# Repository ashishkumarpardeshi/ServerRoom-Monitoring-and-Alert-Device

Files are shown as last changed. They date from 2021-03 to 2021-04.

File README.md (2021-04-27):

# ServerRoom-Monitoring-and-Alert-Device

<p align="center">
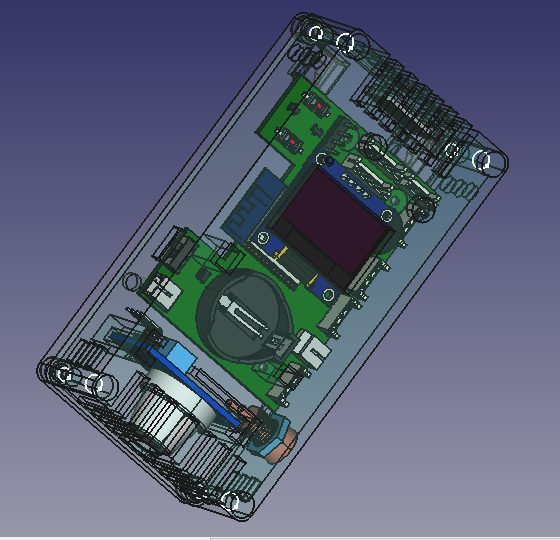
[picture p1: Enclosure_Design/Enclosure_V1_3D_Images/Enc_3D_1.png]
  
</p>

<p align="center">
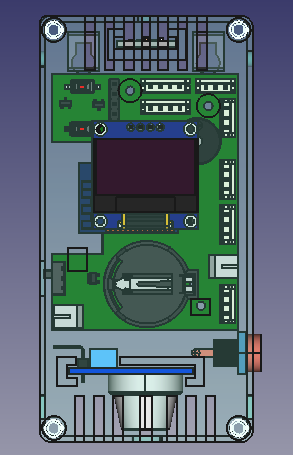
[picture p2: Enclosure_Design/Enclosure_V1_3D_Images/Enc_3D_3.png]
  
</p>

<p align="center">
  
</p>

<p align="center">
  
</p>

<p align="center">
  
</p>

<p align="center">
  
</p>

<p align="center">
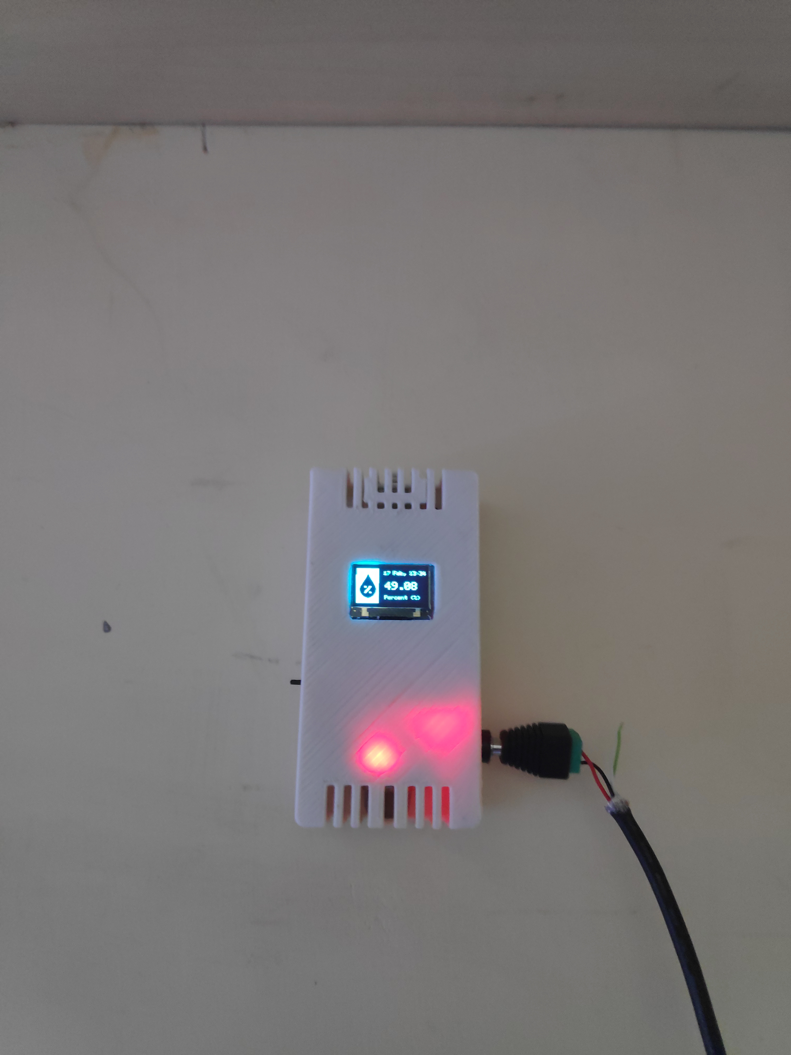
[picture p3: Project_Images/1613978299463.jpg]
  
</p>

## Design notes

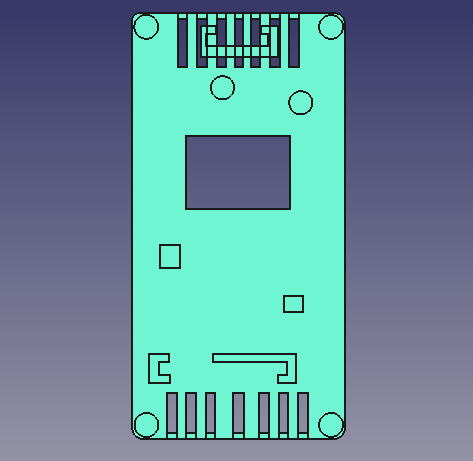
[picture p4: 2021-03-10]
Enclosure_Design/Enclosure_V1_3D_Images/Enc_3D_19.png

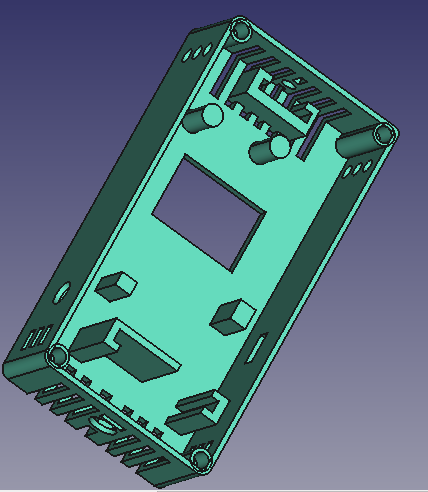
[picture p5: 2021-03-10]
Enclosure_Design/Enclosure_V1_3D_Images/Enc_3D_20.png

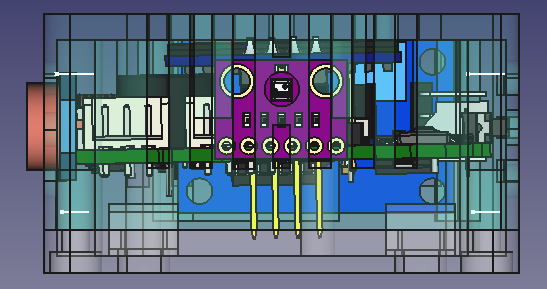
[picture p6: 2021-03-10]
Enclosure_Design/Enclosure_V1_3D_Images/Enc_3D_5.png

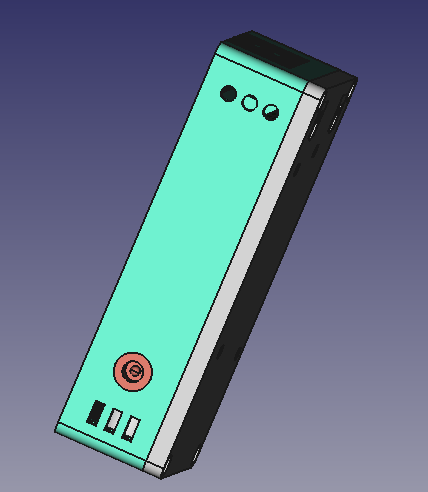
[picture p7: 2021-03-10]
Enclosure_Design/Enclosure_V1_3D_Images/Enc_3D_13.png

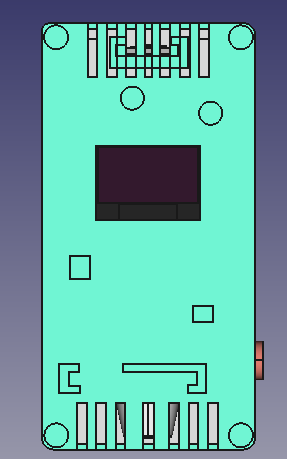
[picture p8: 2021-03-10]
Enclosure_Design/Enclosure_V1_3D_Images/Enc_3D_9.png

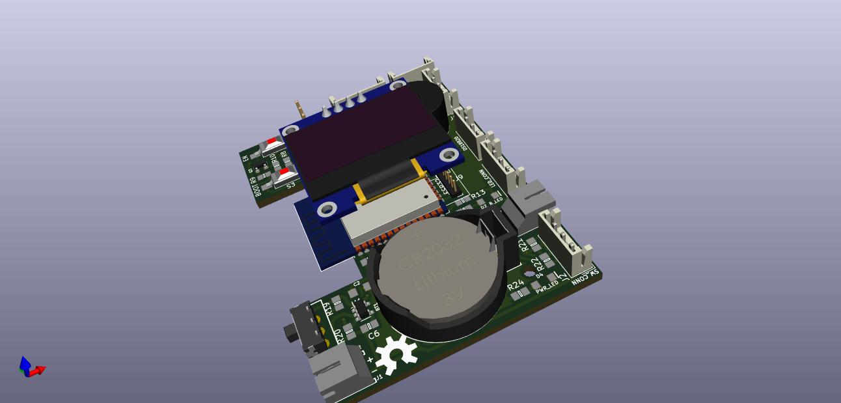
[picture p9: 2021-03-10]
PCB Design/PCB_Images/PWS9.jpg

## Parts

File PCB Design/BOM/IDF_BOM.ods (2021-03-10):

ESP32 Based Generic IoT_Deployement board
Component Count : 64
Individual Components :
Item | Reference(s) | Value | Footprint | Field4
OLED 128 x 64 | Brd1 | SSD1306 | SSD1306:128x64OLED
Battery Holder | BT1 | BAT 20MM PTH | Batteries:BATTCOM_20MM_PTH | BATT-09031
Capacitors | C1 | 1 UF | 805 | CAP-08064
 | C2 | 10UF | Capacitors:EIA3216 | CAP-00811
 | C3 | 0.1 UF | 805 | CAP-08064
 | C4 | 0.1 UF | 805 | CAP-08064
 | C5 | 0.1 UF | 805 | CAP-08064
 | C6 | 470 pF | 805 | CAP-08064
 | C7 | 2.2 uF | 805 | CAP-08064
 | C8 | 10UF | Capacitors:EIA3216 | CAP-00811
 | C9 | 0.1 UF | 805 | CAP-08064
 | C10 | 10UF | Capacitors:EIA3216 | CAP-00811
 | C11 | 0.1 UF | 805 | CAP-08064
Diodes | D1 | 1N4001 | Diode_SMD:D_0805_2012Metric
 | D2 | B_LED | LED:LED-1206 | DIO-09911
 | D3 | 1N4001 | Diode_SMD:D_0805_2012Metric
 | D4 | PWR_LED | LED:LED-1206 | DIO-09911
Connectors (JST & Pin Header) | J1 | PWR | Connectors:JST-2-PTH | CONN-09863
 | J2 | Switch_Conn | Connector_JST:JST_EH_B3B-EH-A_1x03_P2.50mm_Vertical | CONN-13230
 | J3 | Soil_Moisture | Connector_JST:JST_EH_B3B-EH-A_1x03_P2.50mm_Vertical | CONN-13230
 | J4 | LED_CONN | Connector_JST:JST_EH_B3B-EH-A_1x03_P2.50mm_Vertical | CONN-13230
 | J5 | Pump_Conn | Connectors:JST-2-PTH | CONN-09863
 | J6 | BH1750 | Connector_JST:JST_EH_B4B-EH-A_1x04_P2.50mm_Vertical | CONN-13251
 | J7 | HTUI2D | Connector_JST:JST_EH_B4B-EH-A_1x04_P2.50mm_Vertical | CONN-13251
 | J8 | Prog_Header | Connector_PinHeader_2.54mm:PinHeader_1x06_P2.54mm_Vertical
 | J9 | CONN_10 | Connector_PinHeader_1.27mm:PinHeader_1x10_P1.27mm_Vertical | XXX-00000
 | J10 | DHT22 | Connector_JST:JST_EH_B3B-EH-A_1x03_P2.50mm_Vertical | CONN-13230
 | J11 | DS18B20 | Connector_JST:JST_EH_B3B-EH-A_1x03_P2.50mm_Vertical | CONN-13230
Buzzer | LS1 | BUZ-PTH | Electromechanical:BUZZER-12MM | COMP-08253
ESP32 Wroom | MOD1 | ESP32-WROOM | RF_Module:ESP32-WROOM-32
Transistors | Q1 | MMBT2222A2 | Silicon-Standard:SOT23-3 | TRANS-08049
 | Q2 | MMBT2222A2 | Silicon-Standard:SOT23-3 | TRANS-08049
 | Q3 | MMBT2222A2 | Silicon-Standard:SOT23-3 | TRANS-08049
 | Q4 | MMBT2222A2 | Silicon-Standard:SOT23-3 | TRANS-08049
Resistors | R1 | 1k | 805
 | R2 | 10k | 805
 | R3 | 10k | 805
 | R4 | 10k | 805
 | R5 | 470e | 805
 | R6 | 470e | 805
 | R7 | 1k | 805
 | R8 | 10k | 805
 | R9 | 10k | 805
 | R10 | 10k | 805
 | R11 | 10k | 805
 | R12 | 10k | 805
 | R13 | 10k | 805
 | R14 | 470e | 805
 | R15 | 10k | 805
 | R16 | 805 | 805
 | R17 | 805 | 805
 | R18 | 10k | 805
 | R19 | 805 | 805
 | R20 | 805 | 805
 | R21 | 10k | 805
 | R22 | 10k | 805
 | R23 | 470e | 805
 | R24 | 470e | 805
Switches | S1 | ON/OFF | Switches:SWITCH_SPDT_PTH_11.6X4.0MM | SWCH-08261
 | S3 | Boot | Button_Switch_SMD:SW_SPST_FSMSM | SWCH-09213
 | S4 | EN | Button_Switch_SMD:SW_SPST_FSMSM | SWCH-09213
ICs (Voltage Reg, RTC) | U1 | MIC5219-3v3 | Package_TO_SOT_SMD:SOT-23-5
 | U2 | DS3231M | Package_SO:SOIC-16W_7.5x10.3mm_P1.27mm
 | U3 | AMS1117-3.3 | Package_TO_SOT_SMD:SOT-223-3_TabPin2

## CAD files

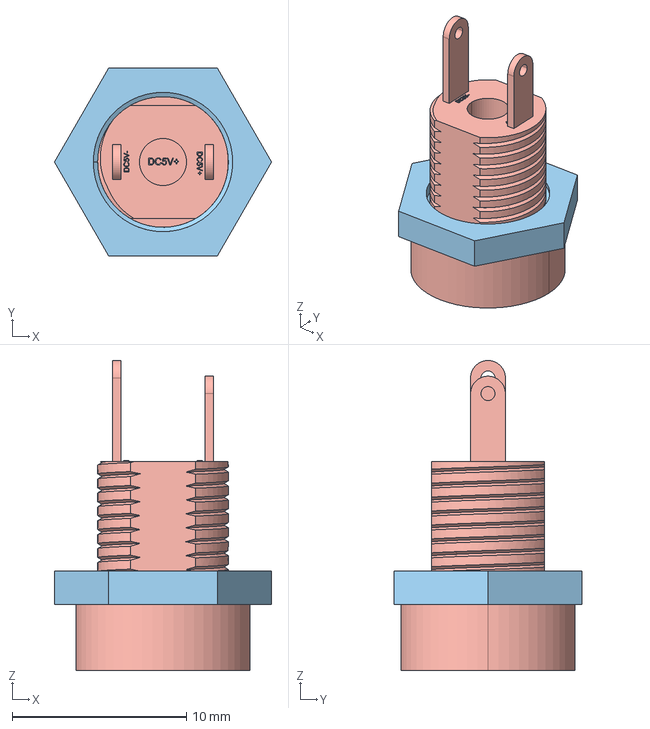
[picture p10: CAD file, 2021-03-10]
Enclosure_Design/Enclosure_V1_FreeCAD_Files/dc5v_jack_asm.stp
12.5 x 10.8 x 17.8 mm
DC5V_JACK
DC5V_JACK_NUTM8

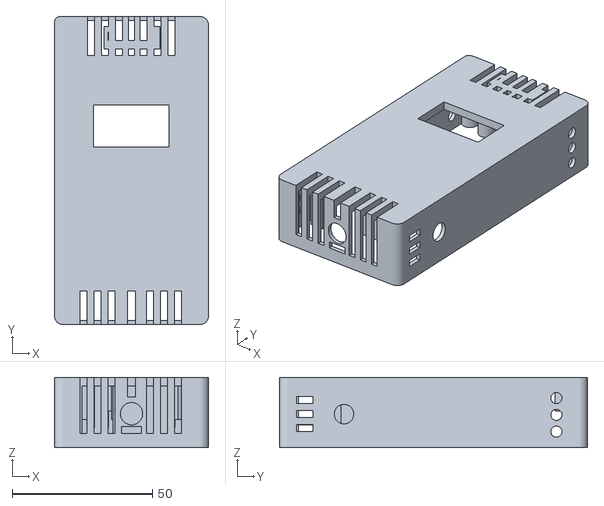
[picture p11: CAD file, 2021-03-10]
Enclosure_Design/Enclosure_V1_FreeCAD_Files/Main_Circuit_Enc.stl
55.0 x 110.0 x 25.0

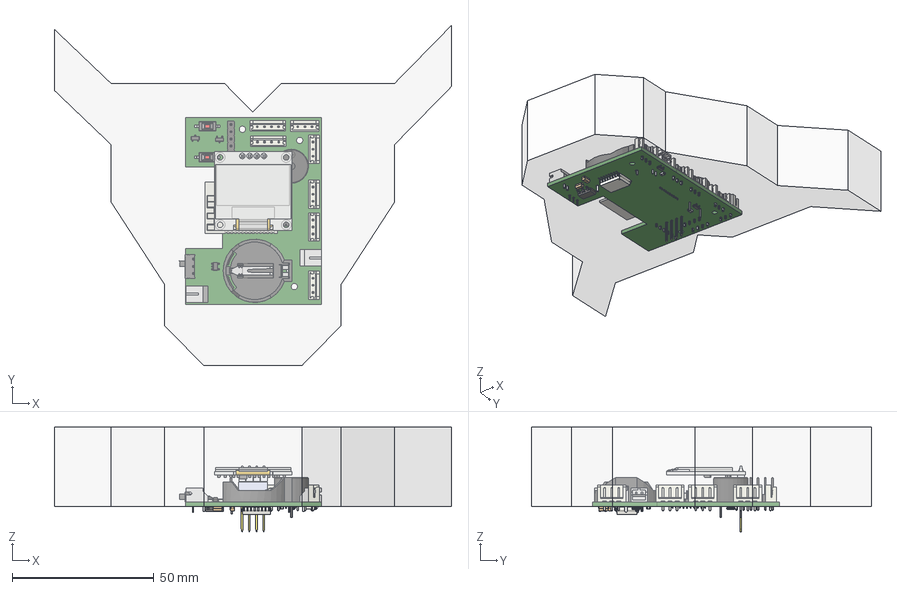
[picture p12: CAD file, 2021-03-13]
Enclosure_Design/Enclosure_V2/Enclosure_V2.FCStd
140.0 x 120.0 x 37.0 mm
Buffalo_Face_Sketch

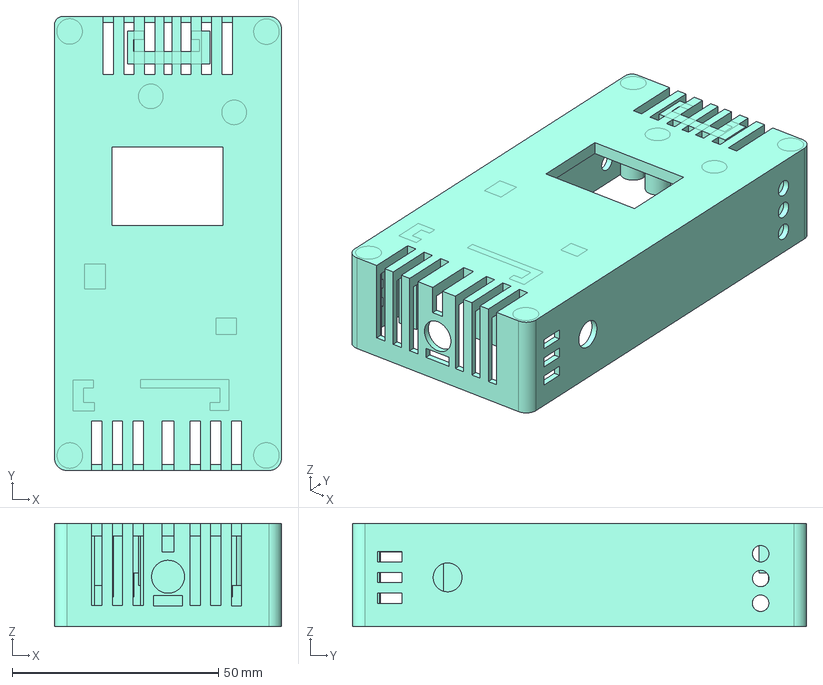
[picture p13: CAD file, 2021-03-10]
Enclosure_Design/Enclosure_V1_FreeCAD_Files/Serverroom_MDev.FCStd
55.0 x 110.0 x 25.0 mm

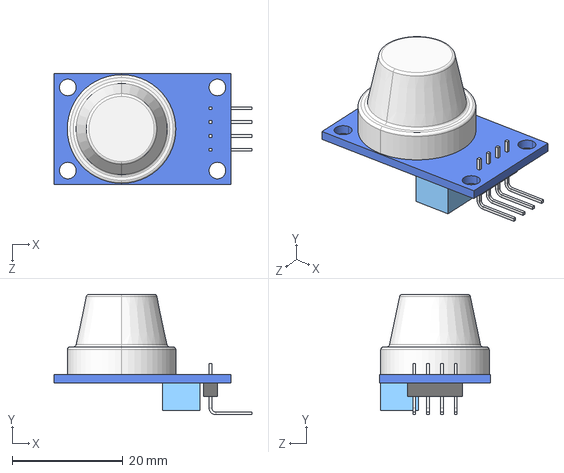
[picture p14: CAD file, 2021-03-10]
Enclosure_Design/Enclosure_V1_FreeCAD_Files/Датчик газа MQ2 (дым).STEP
35.8 x 21.8 x 20.0 mm

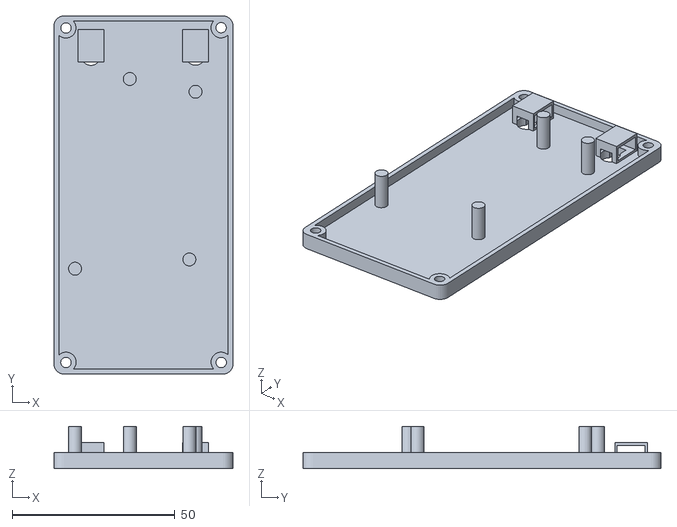
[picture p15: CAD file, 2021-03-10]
Enclosure_Design/Enclosure_V1_FreeCAD_Files/Lid_Enc.stl
55.0 x 110.0 x 13.0

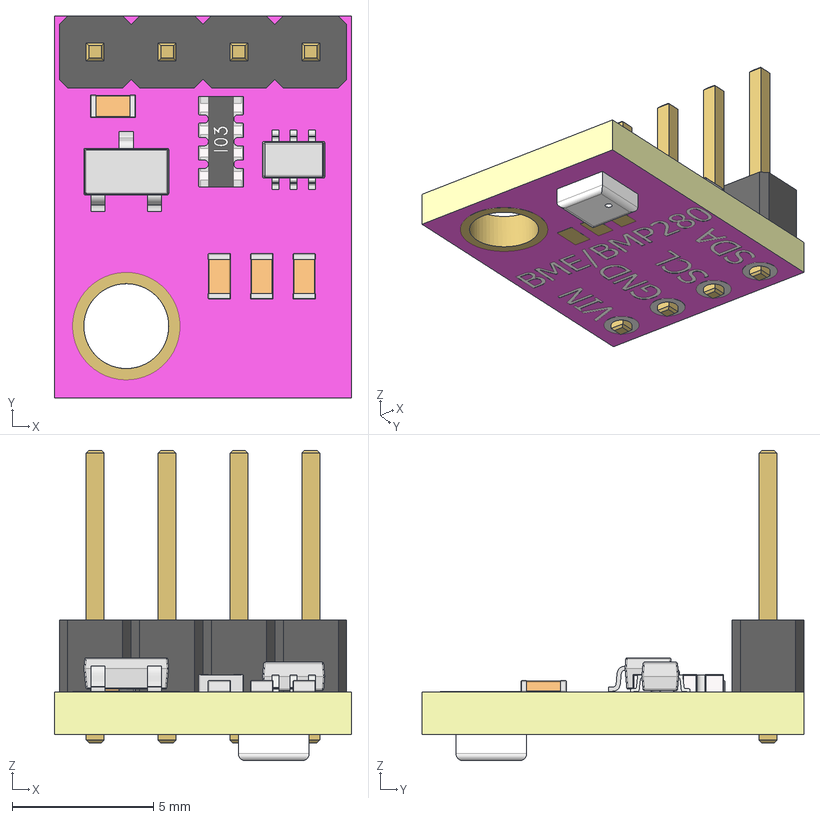
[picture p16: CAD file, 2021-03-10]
Enclosure_Design/Enclosure_V1_FreeCAD_Files/Sensor BME280 (1).stp
10.5 x 13.5 x 11.0 mm
плата датчика BME280
SOT-363
PLS-4
Сборка 0805 4x
SOT23-3

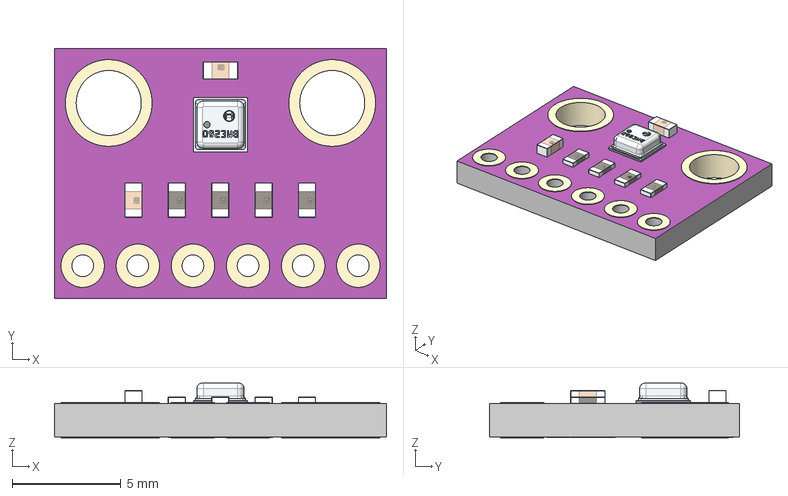
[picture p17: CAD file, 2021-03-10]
Enclosure_Design/Enclosure_V1_FreeCAD_Files/P280, 6-PIN-Version v4 (1).step
15.3 x 11.5 x 2.52 mm
Komponente1
Komponente2
Komponente3
Komponente4
Komponente5
Komponente6
Komponente7
Komponente8
Beschriftung
C0603 x 2
R0603 x 4
BME280

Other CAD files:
Enclosure_Design/Enclosure_V1_FreeCAD_Files/main_enc.step
Enclosure_Design/Enclosure_V1_FreeCAD_Files/lid.step

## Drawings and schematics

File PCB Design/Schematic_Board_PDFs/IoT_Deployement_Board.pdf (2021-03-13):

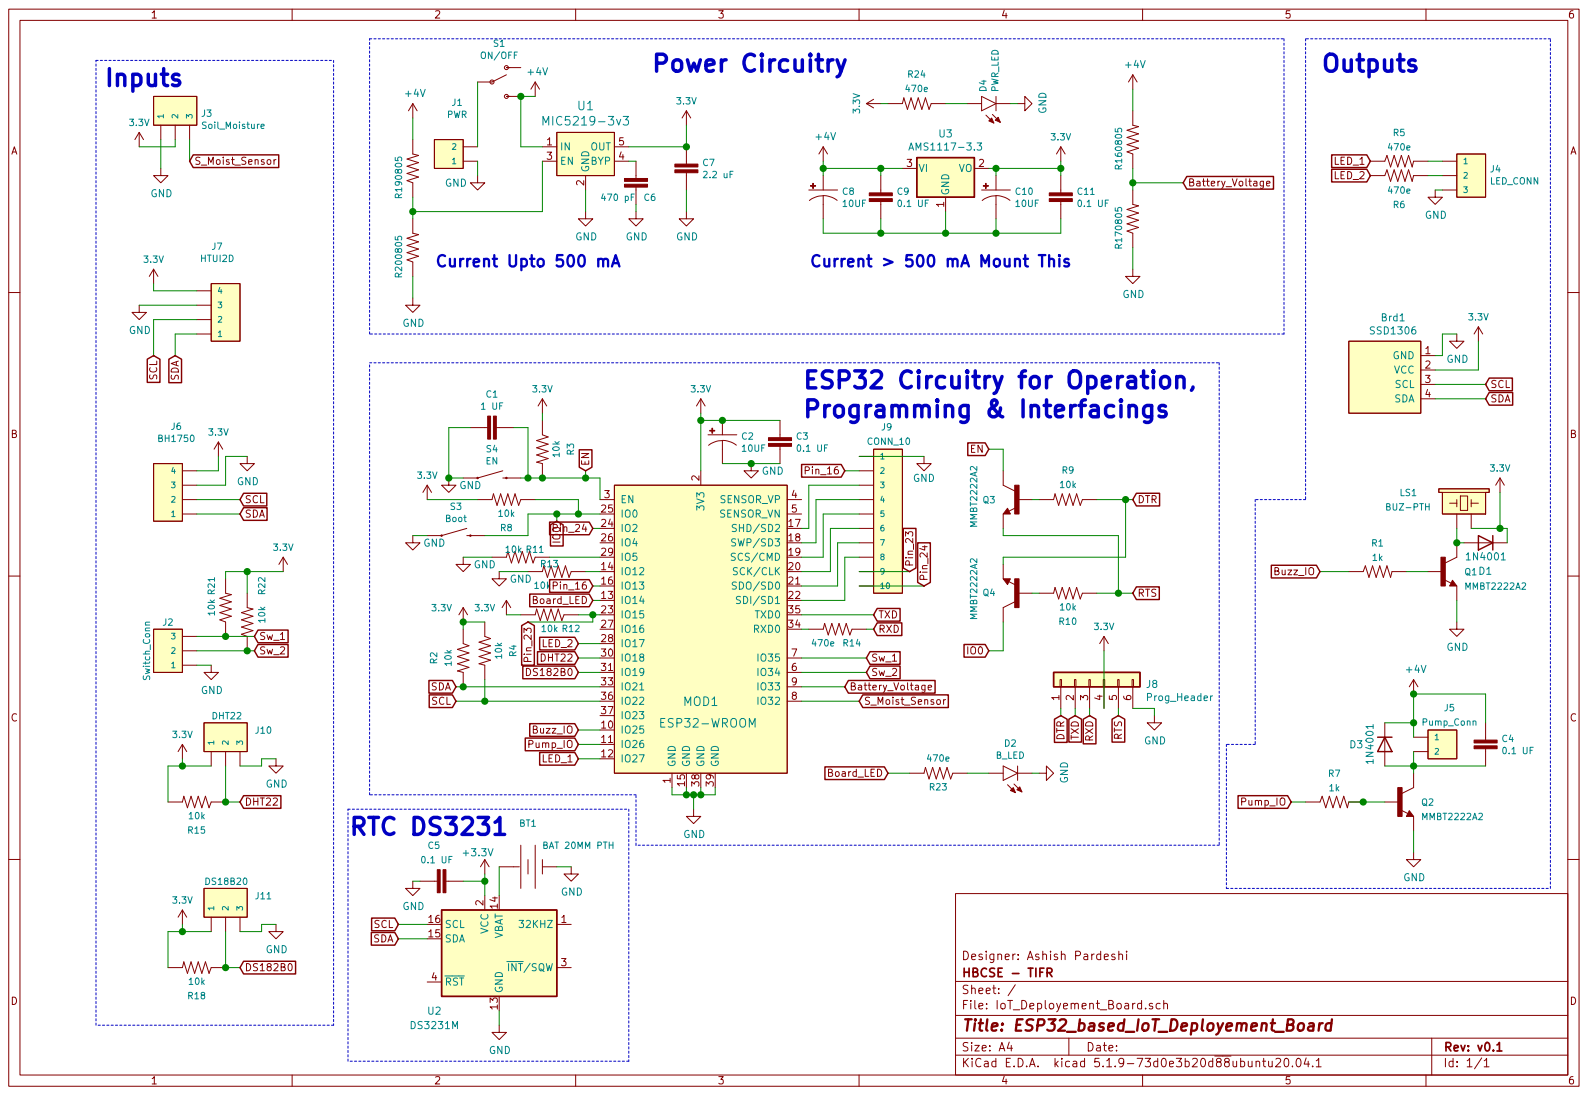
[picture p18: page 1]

Designer: Ashish Pardeshi 470e R14 GND
IO0 SCL

File: IoT_Deployement_Board.sch Sheet: / HBCSE - TIFR

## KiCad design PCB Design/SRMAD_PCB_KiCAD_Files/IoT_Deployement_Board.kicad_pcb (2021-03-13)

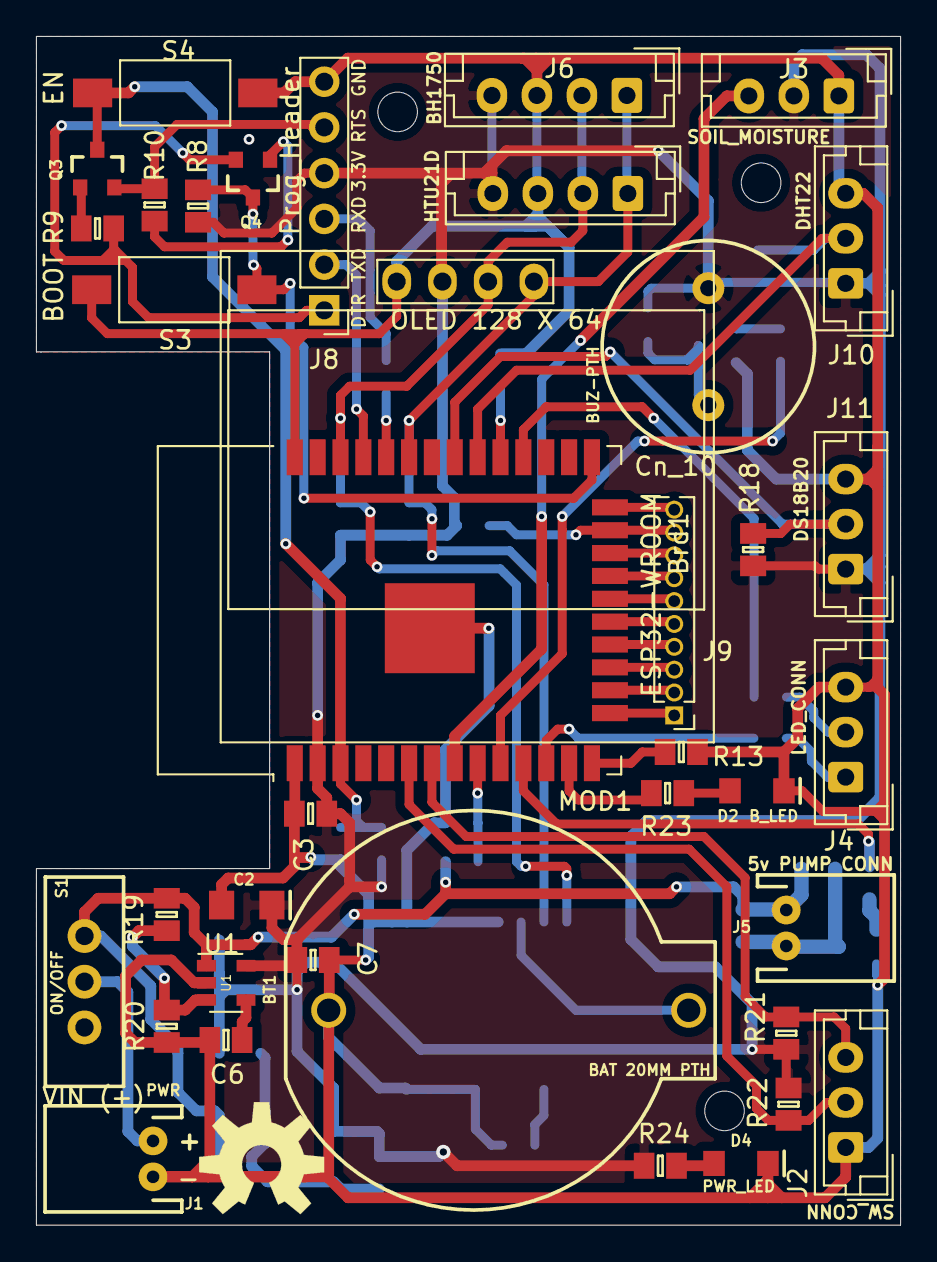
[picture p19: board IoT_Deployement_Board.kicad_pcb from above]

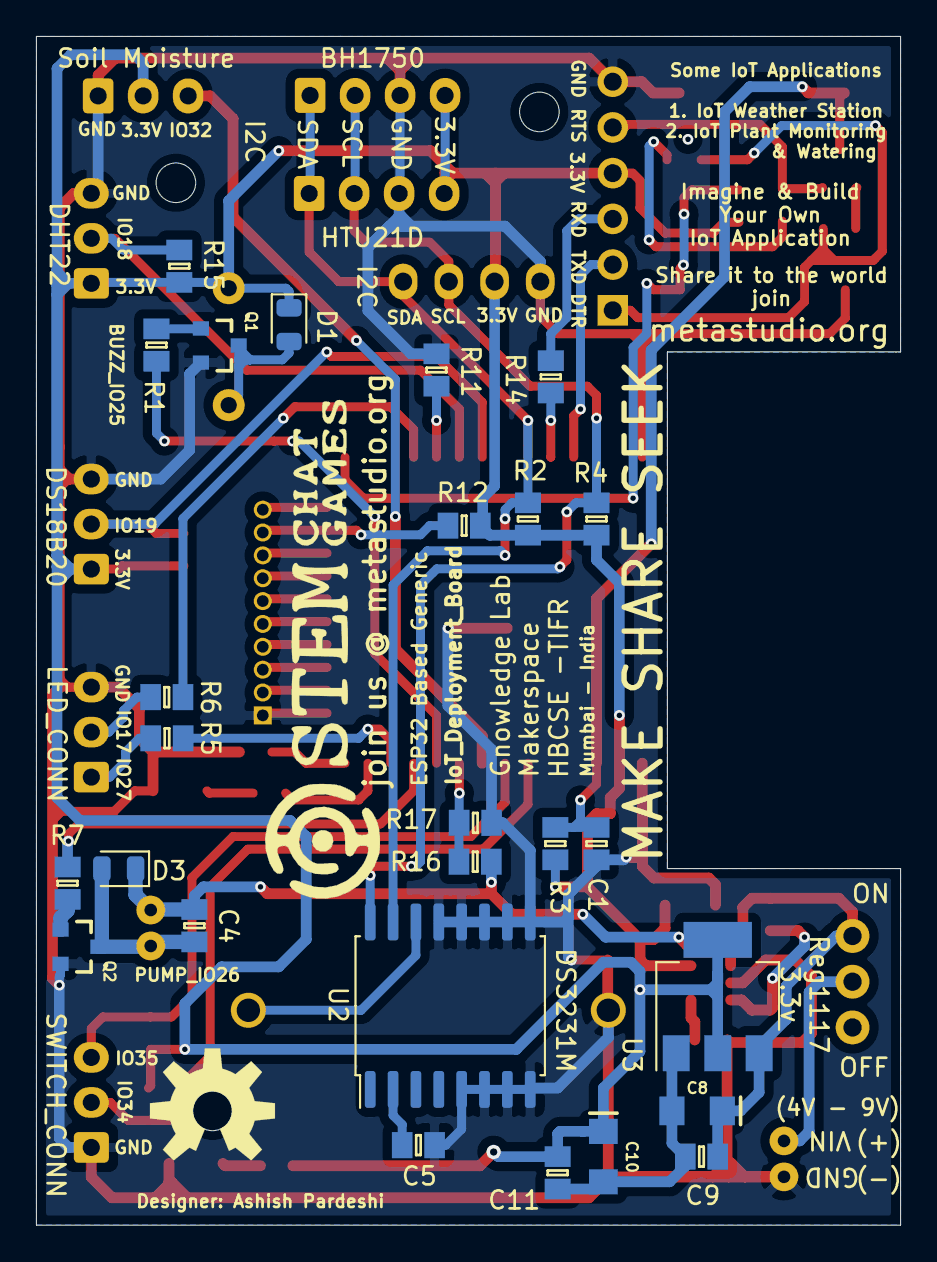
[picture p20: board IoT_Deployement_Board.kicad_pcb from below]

Board: 2 copper layers, 48.0 x 66.0 mm, 64 parts (26 on the bottom side), 50 nets.

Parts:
BT1: BAT 20MM PTH; BATTCOM_20MM_PTH
Brd1: SSD1306; 128x64OLED
C1: 1 UF; 0805
C2, C8, C10: 10UF; EIA3216
C3, C4, C5, C9, C11: 0.1 UF; 0805
C6: 470 pF; 0805
C7: 2.2 uF; 0805
D1, D3: 1N4001; D_0805_2012Metric
D2: B_LED; LED-1206
D4: PWR_LED; LED-1206
J1: PWR; JST-2-PTH
J2: Switch_Conn; JST_EH_B3B-EH-A_1x03_P2.50mm_Vertical
J3: Soil_Moisture; JST_EH_B3B-EH-A_1x03_P2.50mm_Vertical
J4: LED_CONN; JST_EH_B3B-EH-A_1x03_P2.50mm_Vertical
J5: Pump_Conn; JST-2-PTH
J6: BH1750; JST_EH_B4B-EH-A_1x04_P2.50mm_Vertical
J7: HTUI2D; JST_EH_B4B-EH-A_1x04_P2.50mm_Vertical
J8: Prog_Header; PinHeader_1x06_P2.54mm_Vertical
J9: Cn_10; PinHeader_1x10_P1.27mm_Vertical
J10: DHT22; JST_EH_B3B-EH-A_1x03_P2.50mm_Vertical
J11: DS18B20; JST_EH_B3B-EH-A_1x03_P2.50mm_Vertical
LS1: BUZ-PTH; BUZZER-12MM
MOD1: ESP32-WROOM; ESP32-WROOM-32
Q1, Q2, Q3, Q4: MMBT2222A2; SOT23-3
R1, R7: 1k; 0805
R2, R3, R4, R8, R9, R10, R11, R12, R13, R15, R18, R21, R22: 10k; 0805
R5, R6, R14, R23, R24: 470e; 0805
R16, R17, R19, R20: 0805
S1: ON/OFF; SWITCH_SPDT_PTH_11.6X4.0MM
S3: Boot; SW_SPST_FSMSM
S4: EN; SW_SPST_FSMSM
U1: MIC5219-3v3; SOT-23-5
U2: DS3231M; SOIC-16W_7.5x10.3mm_P1.27mm
U3: AMS1117-3.3; SOT-223-3_TabPin2

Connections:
3.3V: Brd1.2, C2.+, C3.1, C7.1, C10.+, C11.1, D1.1, J3.2, J6.4, J7.4, J8.4, J10.1, J11.1, LS1.-, MOD1.2, R2.1, R3.1, R4.1, R8.2, R12.2, R15.2, R18.2, R21.2, R22.2, R24.2, U1.5, U3.2
+3V3: C5.1, U2.2
+4V: C4.1, C8.+, C9.1, D3.1, J5.1, R16.2, R19.2, S1.3, U1.1, U3.3
Battery_Voltage: MOD1.9, R16.1, R17.2
Board_LED: MOD1.13, R23.2
Buzz_IO: MOD1.10, R1.1
DHT22: J10.2, MOD1.30, R15.1
DS182B0: J11.2, MOD1.31, R18.1
DTR: J8.1, Q4.2, R9.1
EN: C1.1, MOD1.3, Q3.3, R3.2, S4.1
GND: BT1.2, Brd1.1, C1.2, C2.-, C3.2, C5.2, C6.2, C7.2, D2.C, D4.C, J1.1, J2.1, J3.1, J4.3, J6.3, J7.3, J8.6, J9.1, J10.3, J11.3, MOD1.1, MOD1.15, MOD1.38, MOD1.39, Q1.2, Q2.2, R11.2, R13.2, R17.1, R20.1, S3.2, S4.2, U1.2, U2.5, U2.6, U2.7, U2.8, U2.9, U2.10, U2.11, U2.12, U2.13
IO0: MOD1.25, Q4.3, R8.1, S3.1
LED_1: MOD1.12, R5.1
LED_2: MOD1.28, R6.1
unnamed: BT1.1, U2.14
unnamed: C4.2, D3.2, J5.2, Q2.3
unnamed: C6.1, U1.4
unnamed: C8.-, C9.2, C10.-, C11.2, U3.1
unnamed: D1.2, LS1.+, Q1.3
unnamed: D2.A, R23.1
unnamed: D4.A, R24.1
unnamed: J1.2, S1.2
unnamed: J4.1, R5.2
unnamed: J4.2, R6.2
unnamed: J9.3, MOD1.17
unnamed: J9.4, MOD1.18
unnamed: J9.5, MOD1.19
unnamed: J9.6, MOD1.20
unnamed: J9.7, MOD1.21
unnamed: J9.8, MOD1.22
unnamed: MOD1.14, R13.1
unnamed: MOD1.29, R11.1
unnamed: MOD1.34, R14.2
unnamed: Q1.1, R1.2
unnamed: Q2.1, R7.2
unnamed: Q3.1, R9.2
unnamed: Q4.1, R10.2
unnamed: R19.1, R20.2, U1.3
Pin_16: J9.2, MOD1.16
Pin_23: J9.9, MOD1.23, R12.1
Pin_24: J9.10, MOD1.24
Pump_IO: MOD1.11, R7.1
RTS: J8.5, Q3.2, R10.1
RXD: J8.3, R14.1
SCL: Brd1.3, J6.2, J7.2, MOD1.36, R4.2, U2.16
SDA: Brd1.4, J6.1, J7.1, MOD1.33, R2.2, U2.15
S_Moist_Sensor: J3.3, MOD1.8
Sw_1: J2.3, MOD1.7, R21.1
Sw_2: J2.2, MOD1.6, R22.1
TXD: J8.2, MOD1.35

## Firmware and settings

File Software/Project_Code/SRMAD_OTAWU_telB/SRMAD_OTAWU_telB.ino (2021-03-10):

/************************************************************************
  Sketch: Serverroom_HBCSE_OTAWU_telB.ino

  Programmer: Ashish Pardeshi

  Description: This sketch will read Temperature & Humidity (BME280)
               ,Smoke Sensor (MQ2) and DateTime Stamp.
               It will display data on OLED.
               It will send data on SNMP.
               It will send data on Telegram.

  Interfacings
  --------------------------------------------------------------------------------
  S.No            Device            Parameters                Peripherals/Pins
  
  1               BME280            Temperature &             I2C (SDA, SCL)
                                    Humidity

  2               MQ2               Smoke                     ADC (IO32)

 
  3               OLED              Display Module            I2C (SDA, SCL)
                  128 x 64   

  4               Buzz_IO           Buzzer                    IO25

  5               BoardLED          ON Board_LED              IO14

  --------------------------------------------------------------------------------
*/


#ifdef ESP32
  #include <WiFi.h>
#else
  #include <ESP8266WiFi.h>
#endif
#include <WebServer.h>
#include <ESPmDNS.h>
#include <Update.h>
#include <WiFiClientSecure.h>
#include <UniversalTelegramBot.h> // Universal Telegram Bot Library written by Brian Lough: https://github.com/witnessmenow/Universal-Arduino-Telegram-Bot
#include <ArduinoJson.h>
#include <Wire.h>

#include <Adafruit_BME280.h>
#include <Adafruit_Sensor.h>

#include <Adafruit_SSD1306.h>

#include <ESP32_tone.h>

#include "DS3231.h"

int melody[] = {
  NOTE_C4, NOTE_G3, NOTE_G3, NOTE_A3, NOTE_G3
};

int noteDurations[] = {
  2, 4, 8, 8, 2
};

int buzzerPin = 25;
//create an instance named buzzer
ESP32_tone buzzer;

const char* host = "esp32";

/* Style */
String style =
"<style>#file-input,input{width:100%;height:44px;border-radius:4px;margin:10px auto;font-size:15px}"
"input{background:#f1f1f1;border:0;padding:0 15px}body{background:#3498db;font-family:sans-serif;font-size:14px;color:#777}"
"#file-input{padding:0;border:1px solid #ddd;line-height:44px;text-align:left;display:block;cursor:pointer}"
"#bar,#prgbar{background-color:#f1f1f1;border-radius:10px}#bar{background-color:#3498db;width:0%;height:10px}"
"form{background:#fff;max-width:258px;margin:75px auto;padding:30px;border-radius:5px;text-align:center}"
".btn{background:#3498db;color:#fff;cursor:pointer}</style>";

/* Login page */
String loginIndex = 
"<form name=loginForm>"
"<h1>Makerspace (121) MAD Login</h1>"
"<input name=userid placeholder='User ID'> "
"<input name=pwd placeholder=Password type=Password> "
"<input type=submit onclick=check(this.form) class=btn value=Login></form>"
"<script>"
"function check(form) {"
"if(form.userid.value=='makerspace' && form.pwd.value=='rocks')"
"{window.open('/serverIndex')}"
"else"
"{alert('Error Password or Username')}"
"}"
"</script>" + style;
 
/* Server Index Page */
String serverIndex = 
"<script src='https://ajax.googleapis.com/ajax/libs/jquery/3.2.1/jquery.min.js'></script>"
"<form method='POST' action='#' enctype='multipart/form-data' id='upload_form'>"
"<input type='file' name='update' id='file' onchange='sub(this)' style=display:none>"
"<label id='file-input' for='file'>   Choose file...</label>"
"<input type='submit' class=btn value='Update'>"
"<br><br>"
"<div id='prg'></div>"
"<br><div id='prgbar'><div id='bar'></div></div><br></form>"
"<script>"
"function sub(obj){"
"var fileName = obj.value.split('\\\\');"
"document.getElementById('file-input').innerHTML = '   '+ fileName[fileName.length-1];"
"};"
"$('form').submit(function(e){"
"e.preventDefault();"
"var form = $('#upload_form')[0];"
"var data = new FormData(form);"
"$.ajax({"
"url: '/update',"
"type: 'POST',"
"data: data,"
"contentType: false,"
"processData:false,"
"xhr: function() {"
"var xhr = new window.XMLHttpRequest();"
"xhr.upload.addEventListener('progress', function(evt) {"
"if (evt.lengthComputable) {"
"var per = evt.loaded / evt.total;"
"$('#prg').html('progress: ' + Math.round(per*100) + '%');"
"$('#bar').css('width',Math.round(per*100) + '%');"
"}"
"}, false);"
"return xhr;"
"},"
"success:function(d, s) {"
"console.log('success!') "
"},"
"error: function (a, b, c) {"
"}"
"});"
"});"
"</script>" + style;


WebServer server(80);

#define DEVICE_ID 1     // 0 for CLAB Server and 1 for Makerspace room

#define BUZZER  25
#define BOARD_LED  14 

#define SMOKE_SENSOR 32

#define SCREEN_WIDTH 128 // OLED display width, in pixels
#define SCREEN_HEIGHT 64 // OLED display height, in pixels
#define OLED_RESET     -1 // Reset pin # (or -1 if sharing Arduino reset pin)

// Creating Adafruit bme object for sensor BME280
Adafruit_BME280 bme;     
RTClib RTC; 
Adafruit_SSD1306 display(SCREEN_WIDTH, SCREEN_HEIGHT, &Wire, OLED_RESET);

#define CHAT_ID *Your Chat ID*

// Initialize Telegram BOT
#define BOTtoken "Your Bot Taoken"  // your Bot Token

WiFiClientSecure client;
UniversalTelegramBot bot(BOTtoken, client);

//Checks for new messages every 1 second.
int botRequestDelay = 1000;
unsigned long lastTimeBotRan;
String macAddr;

unsigned int lastMinute = 0;


// ******** Global Variables *********

char* ssid;//[] = { };

volatile float temperature, humidity;

volatile int smoke;

String messageTH, messageSmoke;

float maxTemp = 40.00;
float maxHumidity = 70.00;
int maxSmoke = 20;


String mon[12] = {"Jan", "Feb", "Mar", "Apr", "May", 
                  "Jun", "Jul", "Aug", "Sep", "Oct", 
                  "Nov", "Dec"
                 };


const unsigned char temprature_bmp [] PROGMEM = {
  0xff, 0xff, 0xff, 0xff, 0xff, 0xff, 0xff, 0xff, 0xff, 0xff, 0xff, 0xff, 0x80, 0xff, 0xff, 0xff, 
  0xff, 0x00, 0x3f, 0xff, 0xff, 0xfe, 0x00, 0x1f, 0xff, 0xff, 0xfc, 0x3e, 0x1f, 0xff, 0xff, 0xfc, 
  0x7f, 0x0f, 0xff, 0xff, 0xf8, 0xff, 0x8f, 0xff, 0xff, 0xf8, 0xff, 0x8f, 0xff, 0xff, 0xf8, 0xff, 
  0xc7, 0xff, 0xff, 0xf8, 0xfc, 0x07, 0xff, 0xff, 0xf8, 0xf8, 0x07, 0xff, 0xff, 0xf8, 0xfc, 0x07, 
  0xff, 0xff, 0xf8, 0xff, 0xc7, 0xff, 0xff, 0xf8, 0xff, 0x87, 0xff, 0xff, 0xf8, 0xfc, 0x07, 0xff, 
  0xff, 0xf8, 0xf8, 0x07, 0xff, 0xff, 0xf8, 0xfc, 0x07, 0xff, 0xff, 0xf8, 0xff, 0x87, 0xff, 0xff, 
  0xf8, 0xff, 0xc7, 0xff, 0xff, 0xf8, 0xfc, 0x07, 0xff, 0xff, 0xf8, 0xf8, 0x07, 0xff, 0xff, 0xf8, 
  0xfc, 0x07, 0xff, 0xff, 0xf8, 0xff, 0xc7, 0xff, 0xff, 0xf8, 0xff, 0xc7, 0xff, 0xff, 0xf8, 0xf3, 
  0xc7, 0xff, 0xff, 0xf8, 0xe1, 0xc7, 0xff, 0xff, 0xf8, 0xe1, 0xc7, 0xff, 0xff, 0xf8, 0xe1, 0xc7, 
  0xff, 0xff, 0xf8, 0xe1, 0xc7, 0xff, 0xff, 0xf8, 0xe1, 0xc7, 0xff, 0xff, 0xf8, 0xe1, 0xc7, 0xff, 
  0xff, 0xf8, 0xe1, 0xc7, 0xff, 0xff, 0xf8, 0xe1, 0xc7, 0xff, 0xff, 0xf8, 0xe1, 0xc7, 0xff, 0xff, 
  0xe0, 0xe1, 0xc3, 0xff, 0xff, 0xc1, 0xc1, 0xc1, 0xff, 0xff, 0x83, 0xc0, 0xf0, 0xff, 0xff, 0x87, 
  0x80, 0xf8, 0x7f, 0xff, 0x0f, 0x00, 0x3c, 0x7f, 0xff, 0x1e, 0x00, 0x1c, 0x3f, 0xfe, 0x1c, 0x00, 
  0x0e, 0x3f, 0xfe, 0x38, 0x00, 0x0e, 0x1f, 0xfe, 0x38, 0x00, 0x07, 0x1f, 0xfc, 0x38, 0x00, 0x07, 
  0x1f, 0xfc, 0x70, 0x00, 0x07, 0x1f, 0xfc, 0x70, 0x00, 0x07, 0x1f, 0xfc, 0x70, 0x00, 0x07, 0x1f, 
  0xfc, 0x38, 0x00, 0x07, 0x1f, 0xfe, 0x38, 0x00, 0x07, 0x1f, 0xfe, 0x38, 0x00, 0x0e, 0x1f, 0xfe, 
  0x1c, 0x00, 0x0e, 0x3f, 0xff, 0x1e, 0x00, 0x1c, 0x3f, 0xff, 0x0f, 0x00, 0x3c, 0x7f, 0xff, 0x87, 
  0xc0, 0xf8, 0x7f, 0xff, 0xc3, 0xff, 0xe0, 0xff, 0xff, 0xe0, 0xff, 0xc1, 0xff, 0xff, 0xf0, 0x1e, 
  0x03, 0xff, 0xff, 0xf8, 0x00, 0x0f, 0xff, 0xff, 0xfe, 0x00, 0x1f, 0xff, 0xff, 0xff, 0x80, 0xff, 
  0xff, 0xff, 0xff, 0xff, 0xff, 0xff, 0xff, 0xff, 0xff, 0xff, 0xff, 0xff, 0xff, 0xff, 0xff, 0xff
};

// 'noun_humidity_2580579', 40x64px
const unsigned char humidity_bmp [] PROGMEM = {
  0xff, 0xff, 0xff, 0xff, 0xff, 0xff, 0xff, 0xff, 0xff, 0xff, 0xff, 0xff, 0xff, 0xff, 0xff, 0xff, 
  0xff, 0xff, 0xff, 0xff, 0xff, 0xff, 0xff, 0xff, 0xff, 0xff, 0xff, 0xff, 0xff, 0xff, 0xff, 0xff, 
  0xff, 0xff, 0xff, 0xff, 0xff, 0xff, 0xff, 0xff, 0xff, 0xff, 0xff, 0xff, 0xff, 0xff, 0xff, 0xf3, 
  0xff, 0xff, 0xff, 0xff, 0xe1, 0xff, 0xff, 0xff, 0xff, 0xe1, 0xff, 0xff, 0xff, 0xff, 0xc0, 0xff, 
  0xff, 0xff, 0xff, 0xc0, 0xff, 0xff, 0xff, 0xff, 0x80, 0x7f, 0xff, 0xff, 0xff, 0x80, 0x7f, 0xff, 
  0xff, 0xff, 0x00, 0x3f, 0xff, 0xff, 0xff, 0x00, 0x1f, 0xff, 0xff, 0xfe, 0x00, 0x1f, 0xff, 0xff, 
  0xfc, 0x00, 0x0f, 0xff, 0xff, 0xfc, 0x00, 0x0f, 0xff, 0xff, 0xf8, 0x00, 0x07, 0xff, 0xff, 0xf0, 
  0x00, 0x03, 0xff, 0xff, 0xf0, 0x00, 0x03, 0xff, 0xff, 0xe0, 0x00, 0x01, 0xff, 0xff, 0xc0, 0x00, 
  0x00, 0xff, 0xff, 0xc0, 0x00, 0x00, 0xff, 0xff, 0x80, 0x00, 0x00, 0x7f, 0xff, 0x80, 0x00, 0x00, 
  0x7f, 0xff, 0x00, 0x00, 0x00, 0x3f, 0xff, 0x00, 0x00, 0x00, 0x3f, 0xfe, 0x00, 0x00, 0x00, 0x1f, 
  0xfe, 0x00, 0x00, 0x00, 0x1f, 0xfc, 0x01, 0xc0, 0xe0, 0x0f, 0xfc, 0x01, 0xc1, 0xe0, 0x0f, 0xfc, 
  0x01, 0xc1, 0xc0, 0x0f, 0xf8, 0x00, 0x03, 0x80, 0x07, 0xf8, 0x00, 0x07, 0x00, 0x07, 0xf8, 0x00, 
  0x0f, 0x00, 0x07, 0xf8, 0x00, 0x1e, 0x00, 0x07, 0xf8, 0x00, 0x3c, 0x00, 0x07, 0xf8, 0x00, 0x78, 
  0x00, 0x0f, 0xfc, 0x00, 0xf0, 0x00, 0x0f, 0xfc, 0x00, 0xe0, 0xc0, 0x0f, 0xfc, 0x01, 0xc0, 0xe0, 
  0x0f, 0xfe, 0x01, 0x80, 0xe0, 0x1f, 0xfe, 0x00, 0x00, 0x00, 0x1f, 0xff, 0x00, 0x00, 0x00, 0x3f, 
  0xff, 0x80, 0x00, 0x00, 0x7f, 0xff, 0x80, 0x00, 0x00, 0x7f, 0xff, 0xe0, 0x00, 0x00, 0xff, 0xff, 
  0xe0, 0x00, 0x01, 0xff, 0xff, 0xf8, 0x00, 0x07, 0xff, 0xff, 0xfe, 0x00, 0x0f, 0xff, 0xff, 0xff, 
  0xc0, 0x7f, 0xff, 0xff, 0xff, 0xff, 0xff, 0xff, 0xff, 0xff, 0xff, 0xff, 0xff, 0xff, 0xff, 0xff, 
  0xff, 0xff, 0xff, 0xff, 0xff, 0xff, 0xff, 0xff, 0xff, 0xff, 0xff, 0xff, 0xff, 0xff, 0xff, 0xff, 
  0xff, 0xff, 0xff, 0xff, 0xff, 0xff, 0xff, 0xff, 0xff, 0xff, 0xff, 0xff, 0xff, 0xff, 0xff, 0xff
};

// 'noun_Smoke_3394237', 40x64px
const unsigned char smoke_bmp [] PROGMEM = {
  0xff, 0xff, 0xff, 0xff, 0xff, 0xff, 0xff, 0xff, 0xff, 0xff, 0xff, 0xff, 0xff, 0xff, 0xff, 0xff, 
  0xff, 0xff, 0xff, 0xff, 0xff, 0xff, 0xff, 0xff, 0xff, 0xff, 0xff, 0xff, 0xff, 0xff, 0xff, 0xff, 
  0xff, 0xff, 0xff, 0xff, 0xff, 0xff, 0xff, 0xff, 0xff, 0xff, 0xff, 0xff, 0xff, 0xff, 0xff, 0xff, 
  0xff, 0xff, 0xff, 0xff, 0xff, 0xff, 0xff, 0xff, 0xff, 0xff, 0xff, 0xff, 0xff, 0xff, 0xff, 0xff, 
  0xff, 0xff, 0xff, 0xff, 0xff, 0xff, 0xff, 0xff, 0xff, 0xff, 0xff, 0xff, 0xff, 0xff, 0xff, 0xff, 
  0xff, 0xff, 0xff, 0xff, 0xff, 0xff, 0xff, 0xff, 0xff, 0xff, 0xff, 0xff, 0xff, 0xff, 0xff, 0xff, 
  0xff, 0xff, 0xff, 0xff, 0xff, 0xff, 0x00, 0xff, 0xff, 0xff, 0xc0, 0x00, 0x03, 0xff, 0xfe, 0x00, 
  0x00, 0x00, 0x7f, 0xf8, 0x00, 0x00, 0x00, 0x1f, 0xf0, 0x07, 0xff, 0xe0, 0x0f, 0xe0, 0x7c, 0x00, 
  0x3f, 0x07, 0xe3, 0x80, 0xff, 0x81, 0xc7, 0xee, 0x3f, 0xe7, 0xfc, 0x77, 0xf9, 0xe0, 0x00, 0x07, 
  0x9f, 0xf7, 0x00, 0x08, 0x00, 0xef, 0xfc, 0x00, 0x00, 0x00, 0x3f, 0xf0, 0x00, 0xff, 0x00, 0x0f, 
  0xf0, 0x0f, 0x81, 0xf0, 0x07, 0xe4, 0x18, 0x00, 0x18, 0x37, 0xf0, 0x30, 0x08, 0x04, 0x07, 0xf0, 
  0x20, 0xc9, 0x04, 0x0f, 0xf8, 0x32, 0x4b, 0x44, 0x1f, 0xfe, 0x12, 0x4a, 0x48, 0x7f, 0xff, 0xdb, 
  0x00, 0x4b, 0xff, 0xff, 0xf8, 0x00, 0x1f, 0xff, 0xff, 0xfd, 0xff, 0x9f, 0xff, 0xff, 0xff, 0x00, 
  0xff, 0xff, 0xff, 0xfe, 0x08, 0x7f, 0xff, 0xff, 0xff, 0x00, 0xff, 0xff, 0xff, 0xff, 0xff, 0xff, 
  0xff, 0xff, 0xff, 0xff, 0xff, 0xff, 0xff, 0xff, 0xff, 0xff, 0xff, 0xff, 0xff, 0xff, 0xff, 0xff, 
  0xff, 0xff, 0xff, 0xff, 0xff, 0xff, 0xff, 0xff, 0xff, 0xff, 0xff, 0xff, 0xff, 0xff, 0xff, 0xff, 
  0xff, 0xff, 0xff, 0xff, 0xff, 0xff, 0xff, 0xff, 0xff, 0xff, 0xff, 0xff, 0xff, 0xff, 0xff, 0xff, 
  0xff, 0xff, 0xff, 0xff, 0xff, 0xff, 0xff, 0xff, 0xff, 0xff, 0xff, 0xff, 0xff, 0xff, 0xff, 0xff, 
  0xff, 0xff, 0xff, 0xff, 0xff, 0xff, 0xff, 0xff, 0xff, 0xff, 0xff, 0xff, 0xff, 0xff, 0xff, 0xff, 
  0xff, 0xff, 0xff, 0xff, 0xff, 0xff, 0xff, 0xff, 0xff, 0xff, 0xff, 0xff, 0xff, 0xff, 0xff, 0xff
};


void setup() 
{
  // initialize serial for debugging
  Serial.begin(9600);

  pinMode(BOARD_LED,OUTPUT);
  pinMode(BUZZER,OUTPUT);
  
  digitalWrite(BUZZER,LOW);
  digitalWrite(BOARD_LED,LOW);

   //initialize buzzer
  buzzer.ESP32_toneB(0);

  //set the compatibleMode of the library
  buzzer.setCompatibleMode(true);

  if(!display.begin(SSD1306_SWITCHCAPVCC, 0x3C)) 
  { // Address 0x3D for 128x64
    Serial.println(F("SSD1306 allocation failed"));
    //for(;;); // Don't proceed, loop forever
  }
  
  display.clearDisplay();
  display.display();
  
  display.setTextSize(2); // Draw 2X-scale text
  display.setTextColor(WHITE);
  display.setCursor(5, 5);
  display.println(F("Makerspace"));
  display.setCursor(0, 25);
  display.println(F("    DIY    "));
  display.setCursor(0, 45);
  display.println(F("  Culture "));
  display.display();
  Serial.println("Welcome");
  delay(3000);
  intro_melody();
  display.clearDisplay();
  display.display();
  
  display.setTextSize(2); // Draw 2X-scale text
  display.setTextColor(WHITE);
  display.setCursor(5, 5);
  display.println(F("Temp & Hum"));
  display.setCursor(0, 25);
  display.println(F("    MAD   "));
  display.setTextSize(1); // Draw 2X-scale text
  display.setTextColor(WHITE);
  display.setCursor(0, 43);
  display.println(F(" Monitoring and Alert"));
  display.setCursor(0, 56);
  display.println(F("       Device        "));
  display.display();
  delay(3000);
  
  // MQ2 pre heat
  display.clearDisplay();
  display.display();
  
  display.setTextSize(1); // Draw 2X-scale text
  display.setTextColor(WHITE);
  display.setCursor(30, 20);
  display.println(F("MQ2 Pre Heat"));
  display.setCursor(30, 50);
  display.println(F("Time Starts"));
  display.display();
  
  Serial.println("MQ2 Pre Heat Starts");
  delay(10000);
  Serial.println("MQ2 Pre Heat Done");
  
  display.clearDisplay();
  display.display();
  
  display.setTextSize(1); // Draw 2X-scale text
  display.setTextColor(WHITE);
  display.setCursor(30, 20);
  display.println(F("MQ2 Pre Heat"));
  display.setCursor(30, 50);
  display.println(F("    Done     "));
  display.display();
  
  // Set WiFi to station mode and disconnect from an AP if it was previously connected
  WiFi.mode(WIFI_STA);
  WiFi.disconnect();
  delay(100);

  Serial.println("Setup Done");

  InitWiFi();

  if (!MDNS.begin(host)) { //http://esp32.local
    Serial.println("Error setting up MDNS responder!");
    while (1) {
      delay(1000);
    }
  }
  Serial.println("mDNS responder started");
  /*return index page which is stored in serverIndex */
  server.on("/", HTTP_GET, []() 
  {
    server.sendHeader("Connection", "close");
    server.send(200, "text/html", loginIndex);
  });
  
  server.on("/serverIndex", HTTP_GET, []() 
  {
    server.sendHeader("Connection", "close");
    server.send(200, "text/html", serverIndex);
  });
  /*handling uploading firmware file */
  server.on("/update", HTTP_POST, []() 
  {
    server.sendHeader("Connection", "close");
    server.send(200, "text/plain", (Update.hasError()) ? "FAIL" : "OK");
    ESP.restart();
  }, []() {
    HTTPUpload& upload = server.upload();
    if (upload.status == UPLOAD_FILE_START) {
      Serial.printf("Update: %s\n", upload.filename.c_str());
      if (!Update.begin(UPDATE_SIZE_UNKNOWN)) { //start with max available size
        Update.printError(Serial);
      }
    } else if (upload.status == UPLOAD_FILE_WRITE) {
      /* flashing firmware to ESP*/
      if (Update.write(upload.buf, upload.currentSize) != upload.currentSize) {
        Update.printError(Serial);
      }
    } else if (upload.status == UPLOAD_FILE_END) {
      if (Update.end(true)) { //true to set the size to the current progress
        Serial.printf("Update Success: %u\nRebooting...\n", upload.totalSize);
      } else {
        Update.printError(Serial);
      }
    }
  });
  server.begin();

  
  if (!bme.begin(0x76)) {
    Serial.println("Could not find a valid BME280 sensor, check wiring!");
    //while (1);
  }


  Wire.begin();

  Serial.println  ("Sensors Done");
}

void loop() 
{
  server.handleClient();

  buzzAlert();
  
  getBmeReadings();
  oledTempHum();
  
  getSmokeReading();
  oledSmoke();

  telegramBotRoutine();
}

void telegramBotRoutine()
{
  
  buzzAlert();
  if (WiFi.status() != WL_CONNECTED) 
  {
    Serial.println("Reconnecting");
    AP_Connection();
  }

  //if (millis() > lastTimeBotRan + botRequestDelay)  
  //{
    int numNewMessages = bot.getUpdates(bot.last_message_received + 1);

    while(numNewMessages) 
    {
      buzzAlert();
      Serial.println("got response");
      handleNewMessages(numNewMessages);
      numNewMessages = bot.getUpdates(bot.last_message_received + 1);
    }
    //lastTimeBotRan = millis();
  //}

  String alertMsg = "HIGH ALERT \n";
  if(DEVICE_ID == 0)
    alertMsg += "CLAB_Server \n";
  else
    alertMsg += "Makerspace (121) \n";
  alertMsg += messageTH;
  alertMsg += messageSmoke;
  buzzAlert();
  if(temperature >= maxTemp || humidity >= maxHumidity || smoke >= maxSmoke)
  {
    bot.sendMessage(CHAT_ID, alertMsg, "");
    //delay(10);
  }

  routineUpdates();
}

void getBmeReadings()
{
  temperature = bme.readTemperature();
  humidity = bme.readHumidity();
  buzzAlert();
  messageTH = "Temperature: " + String(temperature) + " ºC \n";
  messageTH += "Humidity: " + String (humidity) + " % \n";

  /*String strH = String(humidity);
  strH.toCharArray(strHumidity, strH.length());
  String strT = String(temperature);
  strT.toCharArray(strTemperature, strT.length());*/
}

void getSmokeReading()
{
  smoke = analogRead(SMOKE_SENSOR);
  messageSmoke = "Smoke: " + String(smoke) + " \n";
  buzzAlert();
}


void oledTempHum()
{
  buzzAlert();
  display.clearDisplay();
  oledDataTime();
  display.drawBitmap(0, 0,temprature_bmp, 40, 64, WHITE); 

  display.setTextSize(2); // Draw 2X-scale text
  display.setTextColor(WHITE);
  display.setCursor(53, 25);
  display.print(temperature);
  display.setTextSize(1); // Draw 2X-scale text
  display.setCursor(52, 50);
  display.println(F("Deg Celcius"));
  display.display();
  
  
  delay(500);
  buzzAlert();
  display.clearDisplay();
  oledDataTime();
  display.drawBitmap(0, 0,humidity_bmp, 40, 64, WHITE); 

  display.setTextSize(2); // Draw 2X-scale text
  display.setTextColor(WHITE);
  display.setCursor(53, 25);
  display.print(humidity);
  display.setTextSize(1); // Draw 2X-scale text
  display.setCursor(52, 50);
  display.println(F("Percent (%)"));
  display.display();
  delay(500);
}

void oledSmoke()
{
  buzzAlert();
  display.clearDisplay();
  oledDataTime();
  display.drawBitmap(0, 0,smoke_bmp, 40, 64, WHITE); 

  display.setTextSize(2); // Draw 2X-scale text
  display.setTextColor(WHITE);
  display.setCursor(60, 25);
  display.println(smoke);
  display.setTextSize(1); // Draw 2X-scale text
  display.setCursor(52, 50);
  display.println(F("ADC Value"));

  display.display();
  
  delay(500);
}

void routineUpdates()
{
  buzzAlert();
  int i = 0;
  unsigned int intervalMinuteUpdate[4] = {0,15,30,45};
  bool onceFlag = false;
  String routineMsg = " ";
  DateTime now = RTC.now();

  if(now.minute() != lastMinute)
  {
    for(i=0;i<=3;i++)
    {
      if(now.minute() == intervalMinuteUpdate[i])
      {
         onceFlag = true;
         lastMinute = now.minute();
         break;
      }
    }
    
  }
  
  if(onceFlag == true)
  {
    getBmeReadings();
    getSmokeReading();

    if(DEVICE_ID == 0)
      routineMsg = "CLAB_ServerRoom routine Update \n";
    else
      routineMsg = "Makerspace (121) routine Update \n";
      
    routineMsg += messageTH;
    routineMsg += messageSmoke;
    
    bot.sendMessage(CHAT_ID, routineMsg, "");
    
    onceFlag = false;
  }
}

void oledDataTime()
{
  DateTime now = RTC.now();

  String dateTimeStamp;
  dateTimeStamp = String(now.day()) + " " + String(mon[now.month() - 1]) + ", ";
  dateTimeStamp += String(now.hour())+ ":" + String(now.minute());
  //dateTimeStamp = "26 Jan, 20:59";
  display.setTextSize(1); // Draw 2X-scale text
  display.setTextColor(WHITE);
  display.setCursor(50, 5);
  Serial.println(dateTimeStamp);
  display.println(dateTimeStamp);
}

void buzzBeep()
{
  digitalWrite(BUZZER, HIGH);
  delay(500);
  digitalWrite(BUZZER, LOW);
}

void buzzBeepInd()
{
  digitalWrite(BUZZER, HIGH);
  delay(50);
  digitalWrite(BUZZER, LOW);
}

void buzzAlert()
{
  if(temperature >= maxTemp || humidity >= maxHumidity || smoke >= maxSmoke)
  {
    buzzBeep();
  } 
}

void InitWiFi()
{
  Serial.println("Initialising WiFi");
  WiFi.mode(WIFI_STA);
  
  printMacAddress(); 
  
  AP_Connection();  
}
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

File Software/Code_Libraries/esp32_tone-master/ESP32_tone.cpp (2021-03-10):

#include "Arduino.h"
#include "ESP32_tone.h"
#include "esp32-hal-ledc.h"



bool CompatibleToneActive = false;
unsigned long CompatibleToneStopTime = 0;
int CompatibleBuzzerPin = 1;
bool CompatibleBuzzerPinSet = false;
bool CompatibleMode = false;

int BuzzerPin = 1;
unsigned int Frequency, RepeatTone;
unsigned long ToneOffTime, ToneOnTime, ToneDelay;
bool BeepActive = false;

uint8_t PWMChannel = 0;


void ESP32_tone::ESP32_toneB(uint8_t channel)
{
	//PWMChannel = channel;
	xTaskCreate(this->StaticBuzzerTaskStart, "UpdateBuzzer", 10000, (void*)this, 1, NULL);
	
	ledcSetup(PWMChannel, 0, 8);
	ledcWrite(PWMChannel, 125);
}

void ESP32_tone::StaticBuzzerTaskStart(void* _this)
{
	static_cast<ESP32_tone*>(_this)->BuzzerTask();
}

void ESP32_tone::BuzzerTask()
{
	for(;;)
	{
		if(CompatibleMode)
		{
			if(CompatibleToneActive)
			{
				if(millis() > CompatibleToneStopTime)
				{
					this->noTone(CompatibleBuzzerPin);
				}
			}
		}
		else
		{
		    if(BeepActive)
			{
				for(int i = 0; i < RepeatTone; i++)
				{
					ledcAttachPin(BuzzerPin, PWMChannel);
					delay(ToneOnTime);
					ledcDetachPin(BuzzerPin);
					delay(ToneOffTime);
					BeepActive? i = i : i = RepeatTone;
				}
				delay(ToneDelay);
			}
		}
		delay(1);
	}
}

void ESP32_tone::setCompatibleMode(bool useCompatibleMode = true)
{
	CompatibleMode = useCompatibleMode;
}

void ESP32_tone::setCompatibleMode()
{
	CompatibleMode = true;
}

void ESP32_tone::setCompatibleModePin(int pin)
{
	CompatibleBuzzerPin = pin;
}

void ESP32_tone::tone(int pin, unsigned int frequency)
{
	if(CompatibleBuzzerPinSet)
	{
		if(pin == CompatibleBuzzerPin || !CompatibleToneActive)
	    {
		    ledcWriteTone(PWMChannel, frequency);
		    ledcAttachPin(pin, PWMChannel);
			CompatibleBuzzerPin = pin;
		    CompatibleToneStopTime = -1;
		    CompatibleToneActive = true;
	    }
	}
	else
	{
		CompatibleBuzzerPin = pin;
		CompatibleBuzzerPinSet = true;
		this->tone(CompatibleBuzzerPin, frequency);
	}

}

void ESP32_tone::tone(int pin, unsigned int frequency, unsigned long duration)
{
	if(CompatibleBuzzerPinSet)
	{
	    if(pin == CompatibleBuzzerPin || !CompatibleToneActive)
	    {
		    ledcWriteTone(PWMChannel, frequency);
		    CompatibleToneStopTime = millis() + duration;
		    CompatibleToneActive = true;
		    ledcAttachPin(pin, PWMChannel);
			CompatibleBuzzerPin = pin;
	    }
	}
	else
	{
		CompatibleBuzzerPin = pin;
		CompatibleBuzzerPinSet = true;
		this->tone(CompatibleBuzzerPin, frequency, duration);
	}
}

void ESP32_tone::noTone(int pin)
{
	if(pin == CompatibleBuzzerPin && CompatibleBuzzerPinSet)
	{
		ledcDetachPin(CompatibleBuzzerPin);
		if(CompatibleToneActive) CompatibleToneActive = false;
	}
	
	else if(pin == BuzzerPin && BeepActive &&!CompatibleMode)
	{
		BeepActive = false;
		ledcDetachPin(pin);
	}
}

void ESP32_tone::beepForever(int pin, unsigned int frequency, unsigned long toneOnTime, unsigned long toneOffTime, unsigned int repeatTone, unsigned long toneDelay)
{
	if(repeatTone > 0 && !CompatibleMode)
	{
		BuzzerPin = pin;
		Frequency = frequency;
		ToneOnTime = toneOnTime;
		ToneOffTime = toneOffTime;
		RepeatTone = repeatTone;
		ToneDelay = toneDelay;
		BeepActive = true;
		ledcWriteTone(PWMChannel, frequency);
	}
}
